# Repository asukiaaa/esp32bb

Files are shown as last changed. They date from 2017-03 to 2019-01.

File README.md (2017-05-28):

# ESP32BB
A kicad project for ESP-WROOM-32 and breadboard.

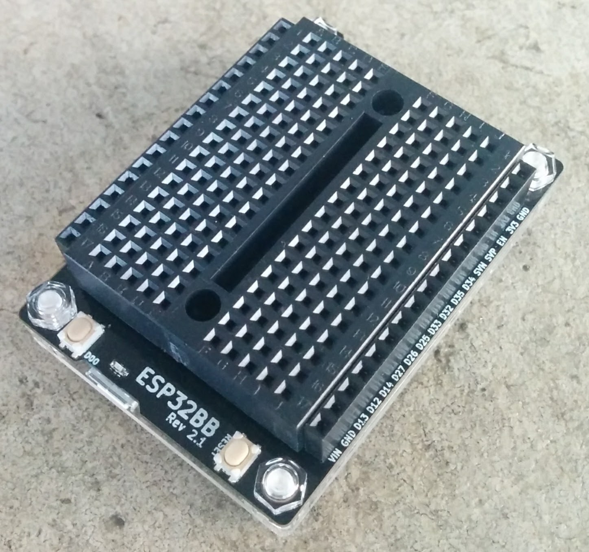
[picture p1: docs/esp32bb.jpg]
ESP32BB

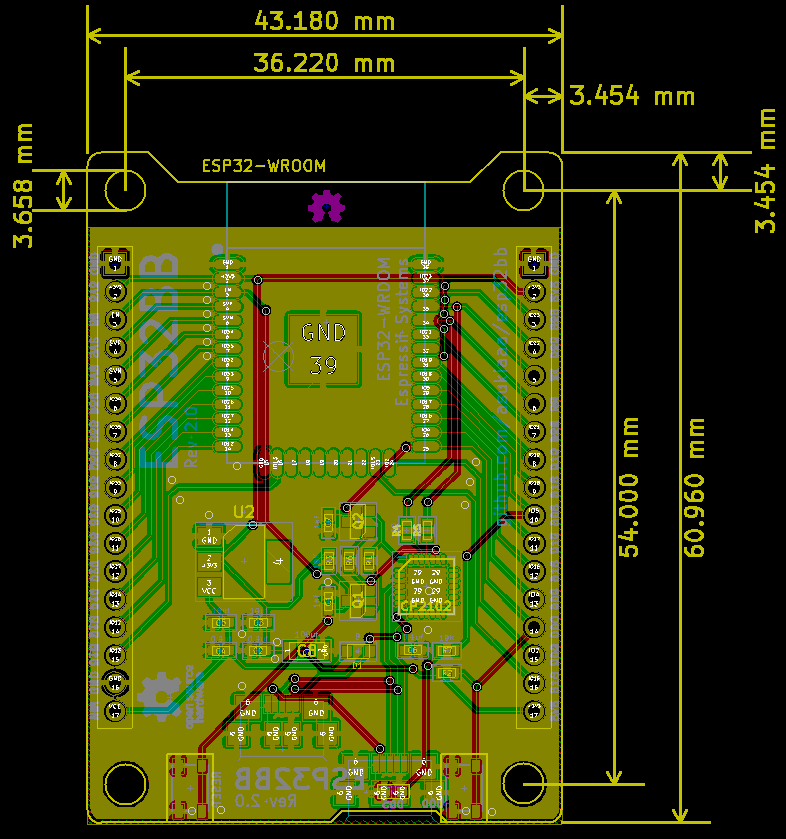
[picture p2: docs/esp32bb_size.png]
ESP32BB_size


[schema](/docs/esp32bb.pdf)

# Driver
This board uses CP2102 for serial communication.
For mac and windiws user, please install the following driver.
Linux supports cp2102 defaul, so linux user does not need any driver.

[CP210x USB to UART Bridge VCP Drivers](http://www.silabs.com/products/development-tools/software/usb-to-uart-bridge-vcp-drivers)

# Shop
[trial stacks](https://trialstacks.base.ec/items/6243312)

# Components
- [esp-wroop-32](http://akizukidenshi.com/catalog/g/gM-11647/)
- [Hirose-microB-USB](http://akizukidenshi.com/catalog/g/gC-05254/)
- [Diode](http://akizukidenshi.com/catalog/g/gI-05951/)
- [transistor MMBT3904](http://akizukidenshi.com/catalog/g/gI-05969/)
- [switch SKRPACE010](http://akizukidenshi.com/catalog/g/gP-06185/)
- [100uf 1206 condensor](http://akizukidenshi.com/catalog/g/gP-08260/)
- [10uf 0603 condensor](http://akizukidenshi.com/catalog/g/gP-07768/)
- [0.1uf 0603 condensor](http://akizukidenshi.com/catalog/g/gP-04940/)
- [1nf (1000pf) 0603 condensor](http://akizukidenshi.com/catalog/g/gP-09285/)
- [10k 0603 registor](http://akizukidenshi.com/catalog/g/gR-06103/)
- [led](http://akizukidenshi.com/catalog/g/gI-06417/)
- [Pin socket](http://akizukidenshi.com/catalog/g/gC-05779/)
- Bread board: [akizuki](http://akizukidenshi.com/catalog/g/gP-05158/) or [aliexpress](https://www.aliexpress.com/item/SYB-170-Mini-Prototype-Experiment-Test-Breadboard-Board-Tie-points-170-Tie-points-35-47-8/32595538101.html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)
- [CP2102](https://www.aliexpress.com/item/5pcs-Free-shipping-SILABS-CP2102-GMR-CP2102-QFN-28-offen-use-laptop-chip-100-new-original/32503317767.html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)
- [NCP1117ST33T3G](https://www.aliexpress.com/item/Free-Shipping-NCP1117ST33T3G-NCP1117-3-3V-linear-regulator-SOT-223-package/32244660148.html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)

# Footprints
- [ESP32-kiCAD-Footprints](https://github.com/adamjvr/ESP32-kiCAD-Footprints)
- [switch: SKRPACE010.kicad_mod](https://github.com/nosuz/kicad-lib/blob/master/module.pretty/SKRPACE010.kicad_mod)

# Programming software tools
ESP32BB is a ESP-WROOM-32 breakout board so you can write your own program by usinig the following tools.

- [espressif/arduino-esp32](https://github.com/espressif/arduino-esp32)
- [espressif/esp-idf](https://github.com/espressif/esp-idf)
- [Mongoose OS](https://mongoose-os.com/)

# License
MIT

# References
- [ESP32-Core-Board-V2_sch.pdf](http://akizukidenshi.com/download/ds/espressifsystems/ESP32-Core-Board-V2_sch.pdf)
- [esp_wroom_32_datasheet_en.pdf](https://espressif.com/sites/default/files/documentation/esp_wroom_32_datasheet_en.pdf)
- [Enginursday: First Impressions of the ESP32](https://www.sparkfun.com/news/2017)
- [ESP32 Development Board with TELEC Memorial photograph](https://macsbug.wordpress.com/2016/12/12/esp32-development-board-with-telec-memorial-photograph/)
- [DS_FT232R](http://www.ftdichip.com/Support/Documents/DataSheets/ICs/DS_FT232R.pdf)
- [SparkFun FTDI Basic Breakout - 3.3V](https://www.sparkfun.com/products/9873)
- [Sehematic of SparkFun FTDI Basic Breakout - 3.3V](http://cdn.sparkfun.com/datasheets/BreakoutBoards/FTDI%20Basic-v22-3.3V.pdf)
- [esp32-thing.sch](https://cdn.sparkfun.com/assets/learn_tutorials/5/0/7/esp32-thing-schematic.pdf)
- [The Internet of Things with ESP32](http://esp32.net/)
- [ESP-WROVER-KIT_SCH-2.pdf](https://dl.espressif.com/dl/schematics/ESP-WROVER-KIT_SCH-2.pdf)
- [ESP32-EVB_Rev_A.pdf](https://github.com/OLIMEX/ESP32-EVB/blob/master/HARDWARE/REV-A/ESP32-EVB_Rev_A.pdf)

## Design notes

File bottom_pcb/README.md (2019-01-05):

# bottom_pcb

- [esp32 hardware design guidelines](https://www.espressif.com/sites/default/files/documentation/esp32_hardware_design_guidelines_en.pdf)

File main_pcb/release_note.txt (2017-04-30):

# rev2.2
- Add diode for 3.3v power

# rev2.1
- Correct circuit around CP2102 chip

# rev2.0
- Replace to CP2102 from FT232RQ
- Remove SD card holder
- Change LED pin to D05
- Use 17pins header for both side

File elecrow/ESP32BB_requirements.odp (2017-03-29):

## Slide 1

Component labels

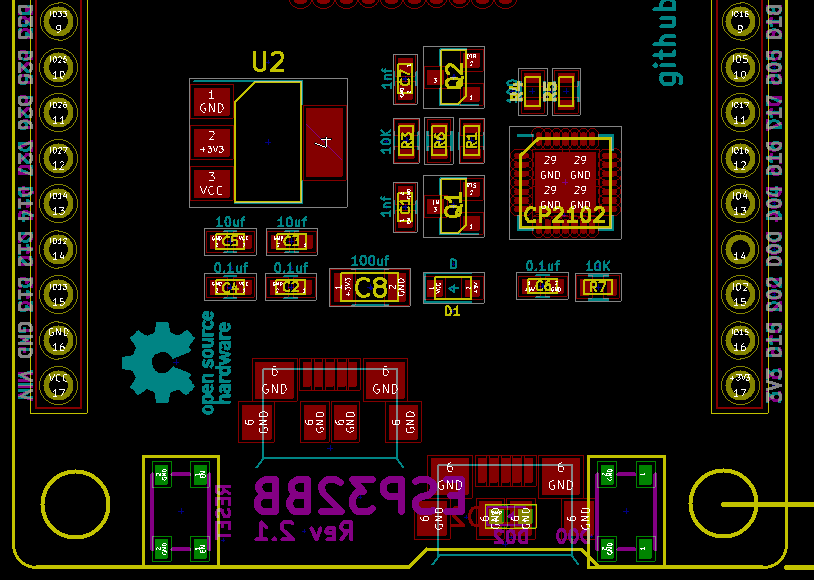
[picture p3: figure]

Front side

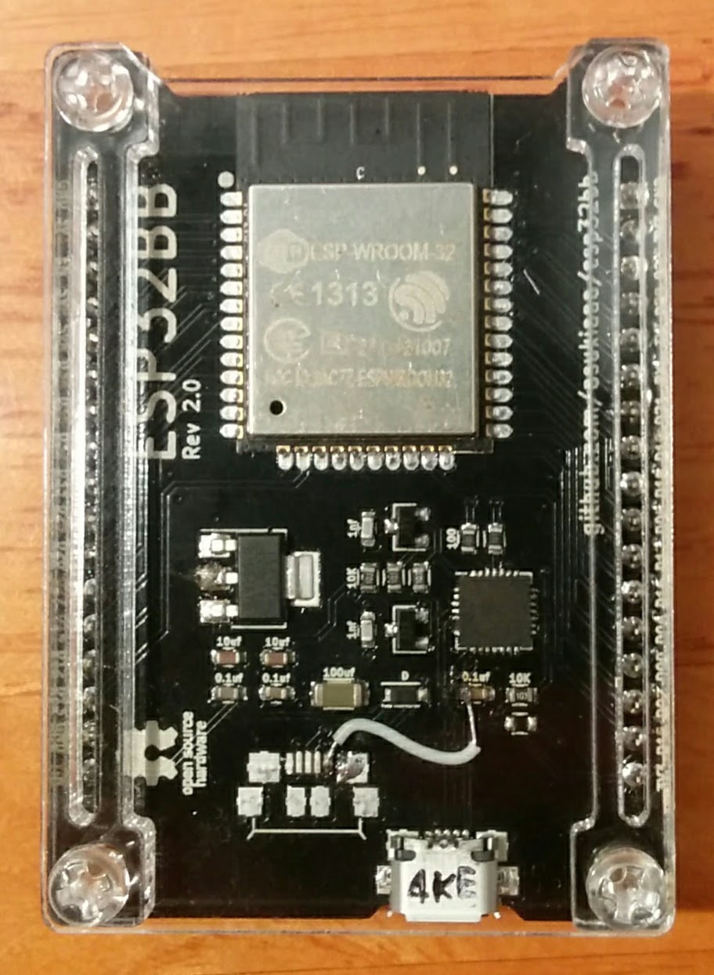
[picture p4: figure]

ESP32 module that has

TELEC mark

Back side

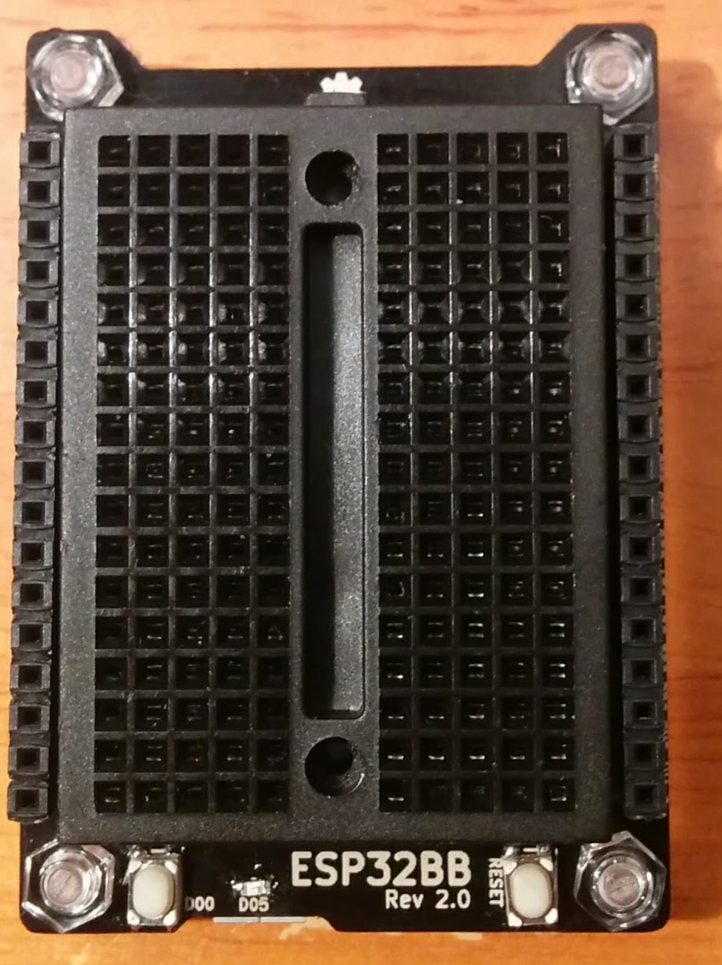
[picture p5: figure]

Please

ignore

bread

board

1x17

Pin

Socket

(female)

Diode

→

←

Diode

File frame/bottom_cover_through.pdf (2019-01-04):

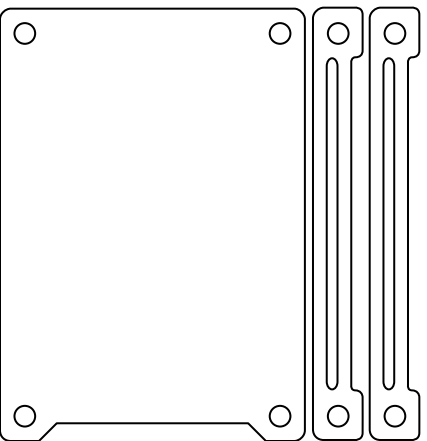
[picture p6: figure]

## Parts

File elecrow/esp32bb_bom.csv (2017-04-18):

Elecrow pn | Reference | Value | Footprint | url | memo
 | P3 | USB_OTG | usb_micro_b:USB_MICRO_B-HIROSE-ZX62R-B-5P | http://www.mouser.jp/ProductDetail/Hirose-Connector/ZX62R-B-5P/?qs=XQjbzJWzFPUqfCc9Mb2Taw==
1023510A(10K) | R1,R3,R6,R7 | 10K | Resistors_SMD:R_0603
 | D1 | D | Diodes_SMD:D_0805 | http://www.mouser.jp/ProductDetail/ROHM-Semiconductor/RSX101VA-30TR/?qs=4kLU8WoGk0tB41wg4aRbGQ==
2013010A(100nf) | C2,C4,C6 | 0.1uf | Capacitors_SMD:C_0603
2015010A(10uf) | C3,C5 | 10uf | Capacitors_SMD:C_0603
 | U1 | ESP32-WROOM | ESP32-footprints-Lib:ESP32-WROOM | http://akizukidenshi.com/catalog/g/gM-11850/ | Please use ESP-WROOM-32 module that has TELEC mark.
 | P1,P2 | CONN_01X17 | common:Pin_Header_Straight_1x17_Pitch2.54mm |  | Foot print is header(male) but use socket (female) component.
10240102A(100) | R4,R5 | 100 | Resistors_SMD:R_0603
4020290A | Q1,Q2 | MMBT3904 | TO_SOT_Packages_SMD:SOT-23
 | SW1,SW2 | SWITCH_SPST | switch:SKRPACE010 | http://www.mouser.jp/ProductDetail/ALPS/SKRPACE010/?qs=m0BA540hBPehI%2flbUxNGuw==
4040706A(green) | D2 | D02 | LEDs:LED_0603
2011501A(1nf) | C1,C7 | 1nf | Capacitors_SMD:C_0603
 | C8 | 100uf | Capacitors_SMD:C_1206 | http://www.mouser.jp/ProductDetail/Taiyo-Yuden/JMK316ABJ107ML-T/?qs=CNQs48zzdnrnxCTArzOO1A==
 | U3 | CP2102 | Housings_DFN_QFN:QFN-28-1EP_5x5mm_Pitch0.5mm | http://www.mouser.jp/ProductDetail/Silicon-Labs/CP2102N-A01-GQFN28/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
 | U2 | NCP1117ST33T3G | TO_SOT_Packages_SMD:SOT-223 | http://www.mouser.jp/ProductDetail/ON-Semiconductor/NCP1117ST33T3G/

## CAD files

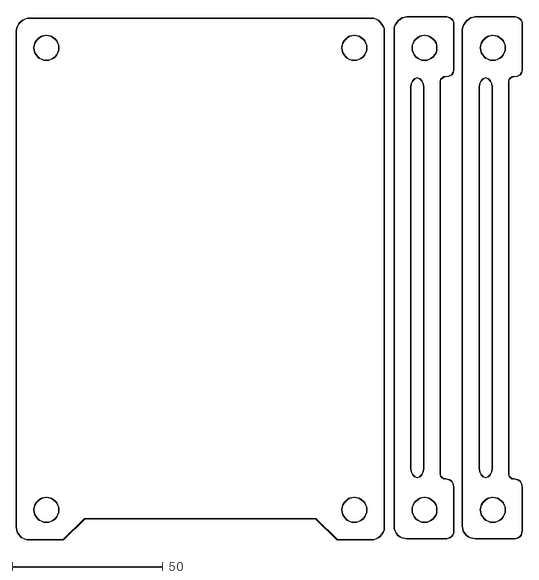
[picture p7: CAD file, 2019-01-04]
frame/bottom_cover_through.dxf
167.7 x 173.6

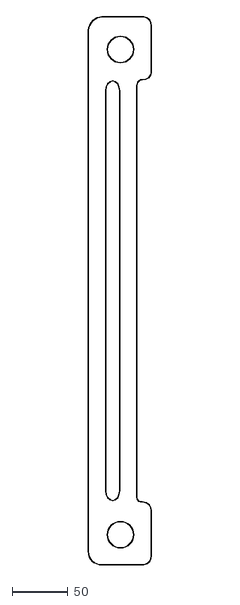
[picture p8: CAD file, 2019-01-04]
frame/bottom_cover_through_7x61x3mm.dxf
56.4 x 490.9

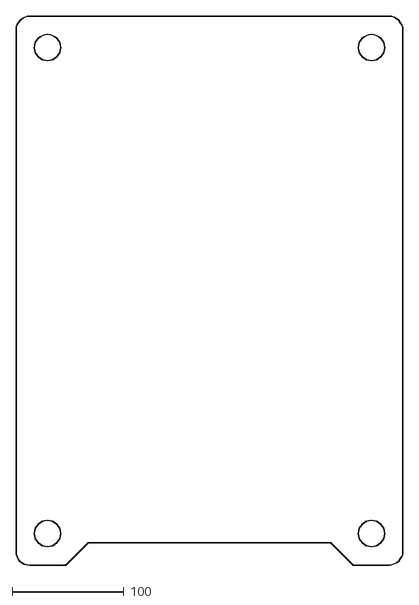
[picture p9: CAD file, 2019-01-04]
frame/bottom_cover_through_42x61x2mm.dxf
345.5 x 490.3

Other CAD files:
frame/export/bottom_cover_through.dxf
frame/export/bottom_cover_through_42x61x2mm.dxf
frame/export/bottom_cover_through_7x61x3mm.dxf

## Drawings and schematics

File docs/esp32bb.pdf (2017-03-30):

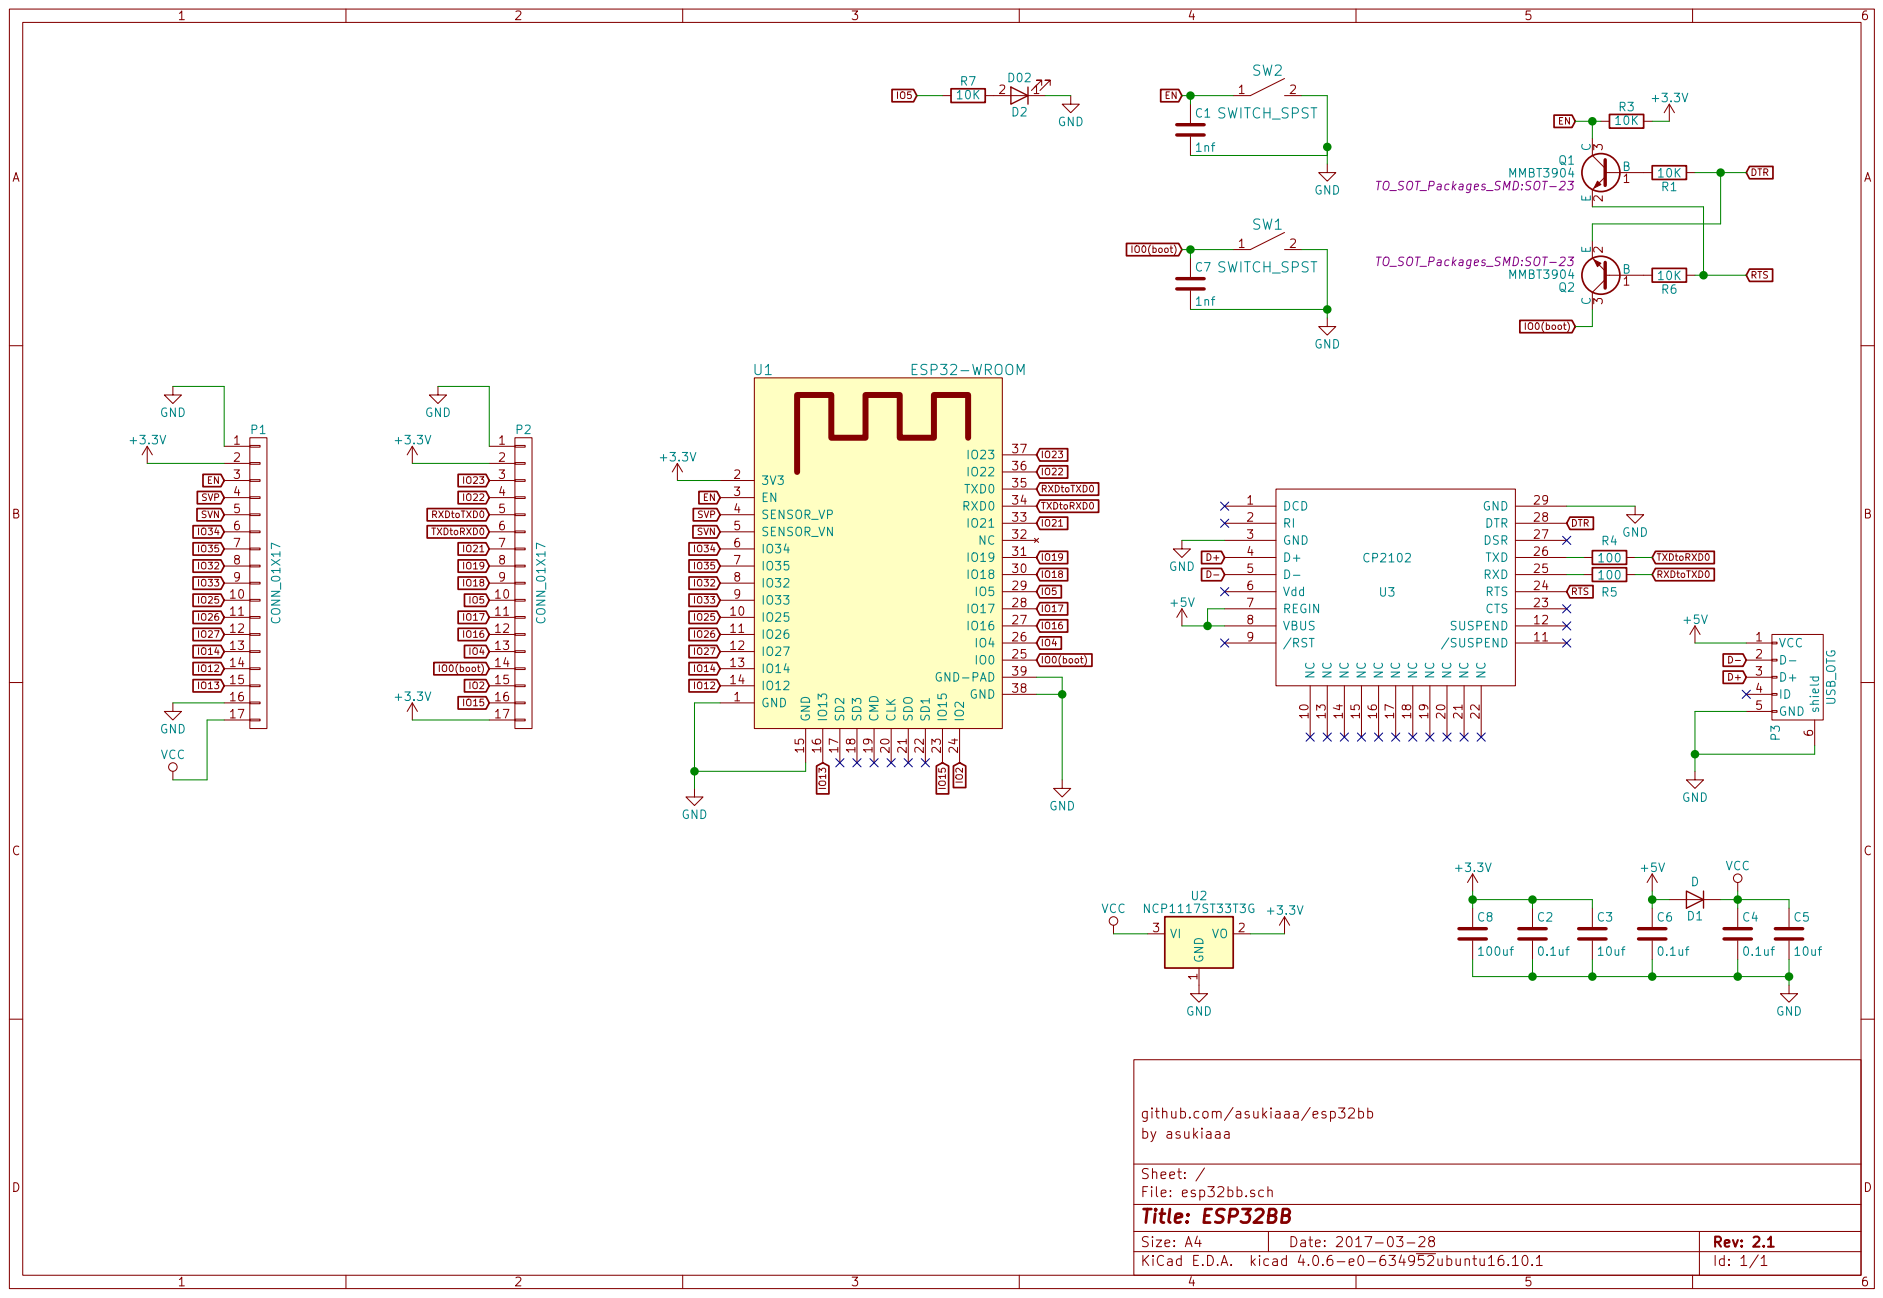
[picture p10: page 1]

github.com/asukiaaa/esp32bb
File: esp32bb.sch Sheet: / by asukiaaa

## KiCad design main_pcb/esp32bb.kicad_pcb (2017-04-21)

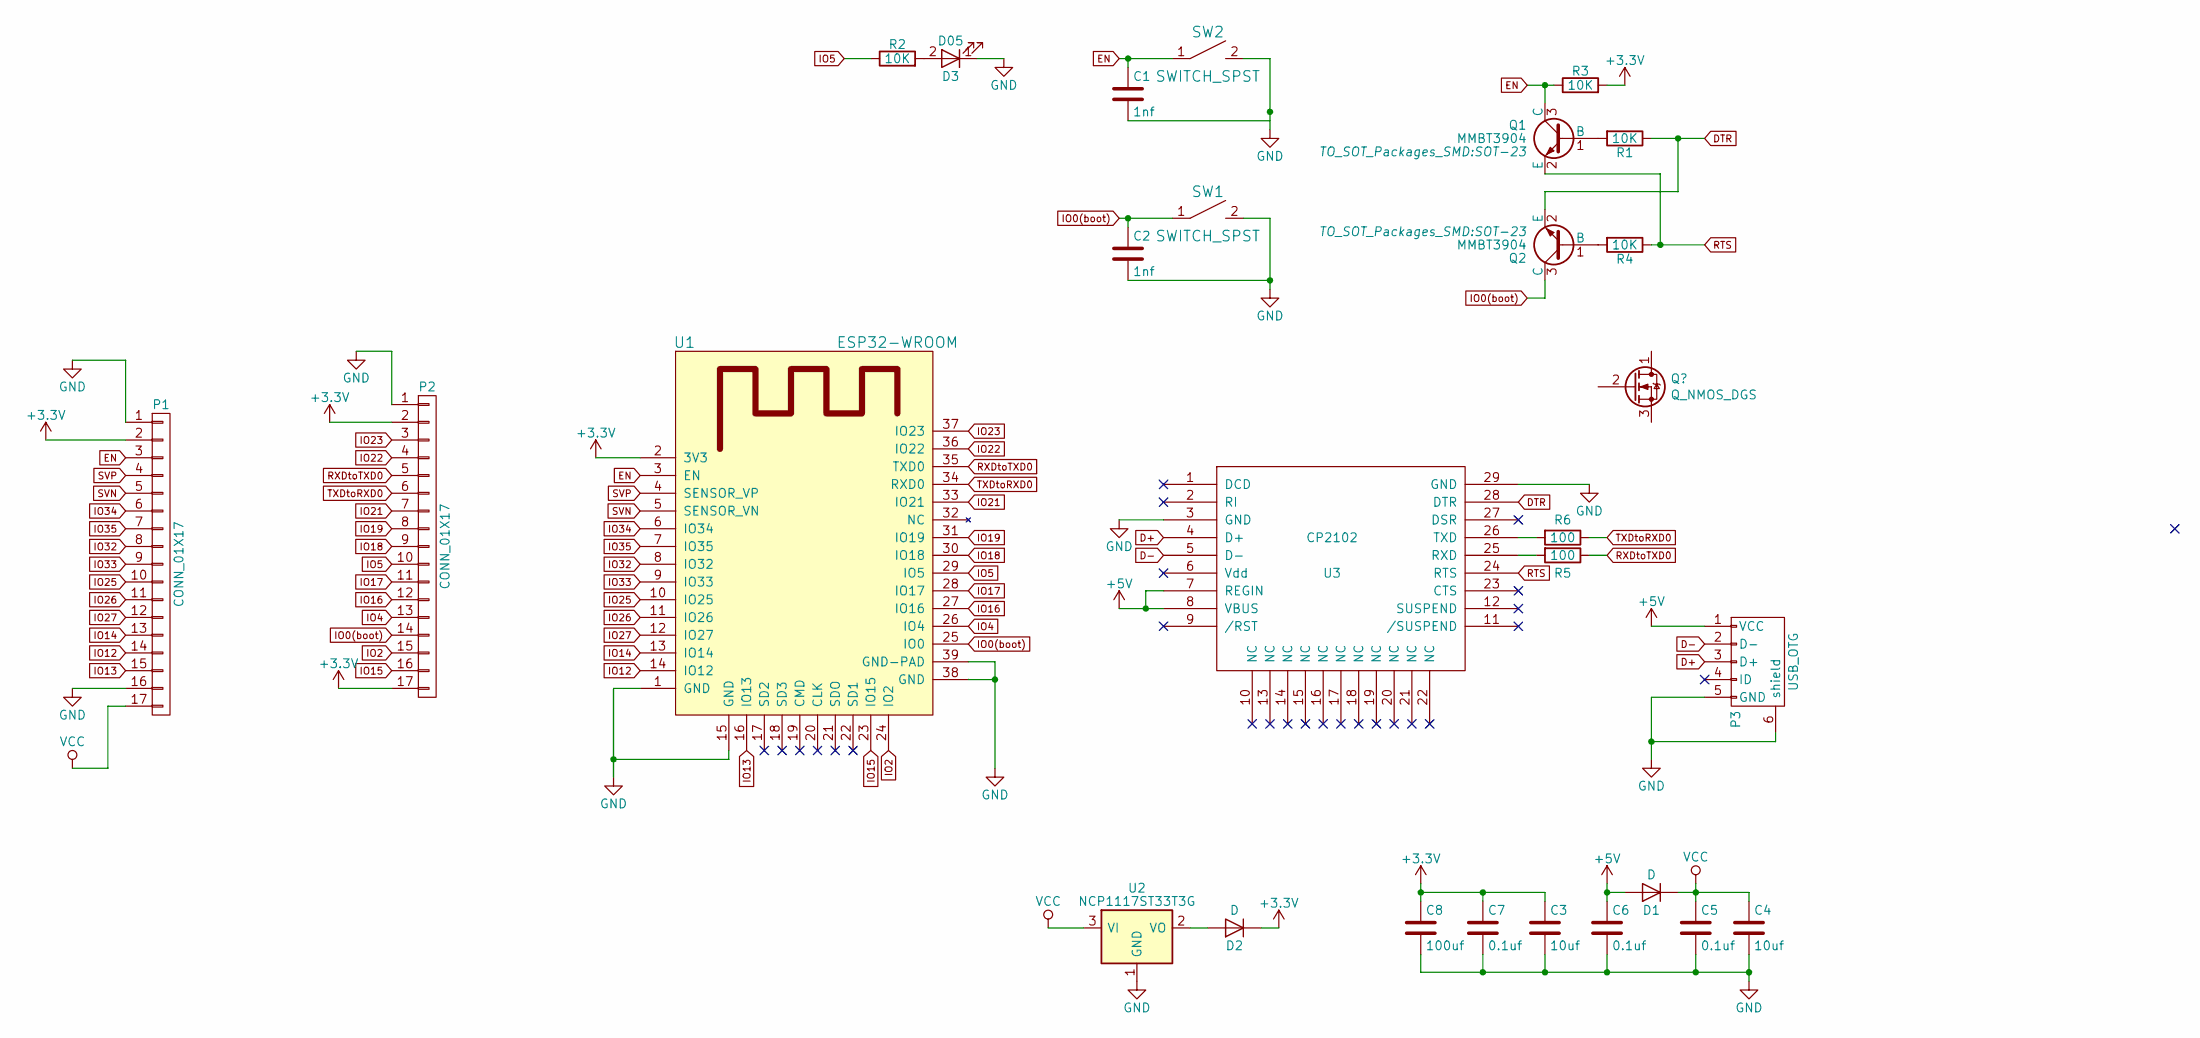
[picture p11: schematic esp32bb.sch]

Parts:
C1, C2: 1nf; C_0603
C3, C4: 10uf; C_0603
C5, C6, C7: 0.1uf; C_0603
C8: 100uf; C_1206
D1, D2: D; D_0805
D3: D05; LED_0603
P1, P2: CONN_01X17; Pin_Header_Straight_1x17_Pitch2.54mm
P3: USB_OTG; USB_MICRO_B-HIROSE-ZX62R-B-5P
Q1, Q2: MMBT3904; SOT-23
R1, R2, R3, R4: 10K; R_0603
R5, R6: 100; R_0603
SW1, SW2: SWITCH_SPST; SKRPACE010
U1: ESP32-WROOM
U2: NCP1117ST33T3G; SOT-223
U3: CP2102; QFN-28-1EP_5x5mm_Pitch0.5mm

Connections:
+3V3: C3.1, C7.1, C8.1, D2.1 (K), P1.2, P2.2, P2.17, R3.2, U1.2 (3V3)
+5V: C6.1, D1.2 (A), P3.1 (VCC), U3.7 (REGIN), U3.8 (VBUS); also elsewhere on the board
D+: P3.3 (D+), U3.4 (D+); also elsewhere on the board
D-: P3.2 (D-), U3.5 (D-); also elsewhere on the board
DTR: Q2.2 (E), R1.1, U3.28 (DTR)
EN: C1.1, P1.3, Q1.3 (C), R3.1, SW2.1, U1.3 (EN)
GND: C1.2, C2.2, C3.2, C4.2, C5.2, C6.2, C7.2, C8.2, D3.1 (K), P1.1, P1.16, P2.1, P3.5 (GND), P3.6 (shield), SW1.2, SW2.2, U1.1 (GND), U1.15 (GND), U1.38 (GND), U1.39 (GND-PAD), U2.1 (GND), U3.3 (GND), U3.29 (GND); also elsewhere on the board
IO0(boot): C2.1, P2.14, Q2.3 (C), SW1.1, U1.25 (IO0)
IO2: P2.15, U1.24 (IO2)
IO4: P2.13, U1.26 (IO4)
IO5: P2.10, R2.1, U1.29 (IO5)
IO12: P1.14, U1.14 (IO12)
IO13: P1.15, U1.16 (IO13)
IO14: P1.13, U1.13 (IO14)
IO15: P2.16, U1.23 (IO15)
IO16: P2.12, U1.27 (IO16)
IO17: P2.11, U1.28 (IO17)
IO18: P2.9, U1.30 (IO18)
IO19: P2.8, U1.31 (IO19)
IO21: P2.7, U1.33 (IO21)
IO22: P2.4, U1.36 (IO22)
IO23: P2.3, U1.37 (IO23)
IO25: P1.10, U1.10 (IO25)
IO26: P1.11, U1.11 (IO26)
IO27: P1.12, U1.12 (IO27)
IO32: P1.8, U1.8 (IO32)
IO33: P1.9, U1.9 (IO33)
IO34: P1.6, U1.6 (IO34)
IO35: P1.7, U1.7 (IO35)
unnamed: D2.2 (A), U2.2 (VO)
unnamed: D3.2 (A), R2.2
unnamed 31: P3.4 (ID); also elsewhere on the board
unnamed: Q1.1 (B), R1.2
unnamed: Q2.1 (B), R4.2
unnamed: R5.2, U3.25 (RXD)
unnamed: R6.2, U3.26 (TXD)
RTS: Q1.2 (E), R4.1, U3.24 (RTS)
RXDtoTXD0: P2.5, R5.1, U1.35 (TXD0)
SVN: P1.5, U1.5 (SENSOR_VN)
SVP: P1.4, U1.4 (SENSOR_VP)
TXDtoRXD0: P2.6, R6.1, U1.34 (RXD0)
VCC: C4.1, C5.1, D1.1 (K), P1.17, U2.3 (VI)

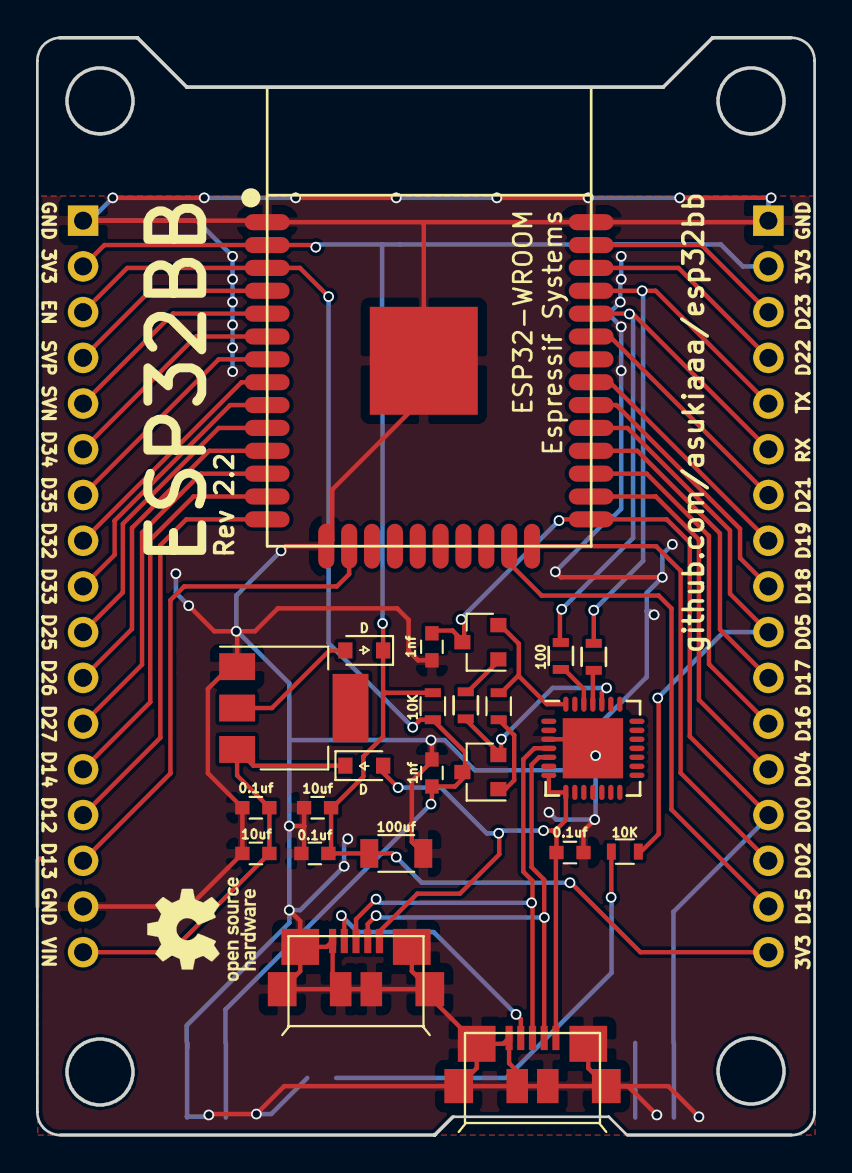
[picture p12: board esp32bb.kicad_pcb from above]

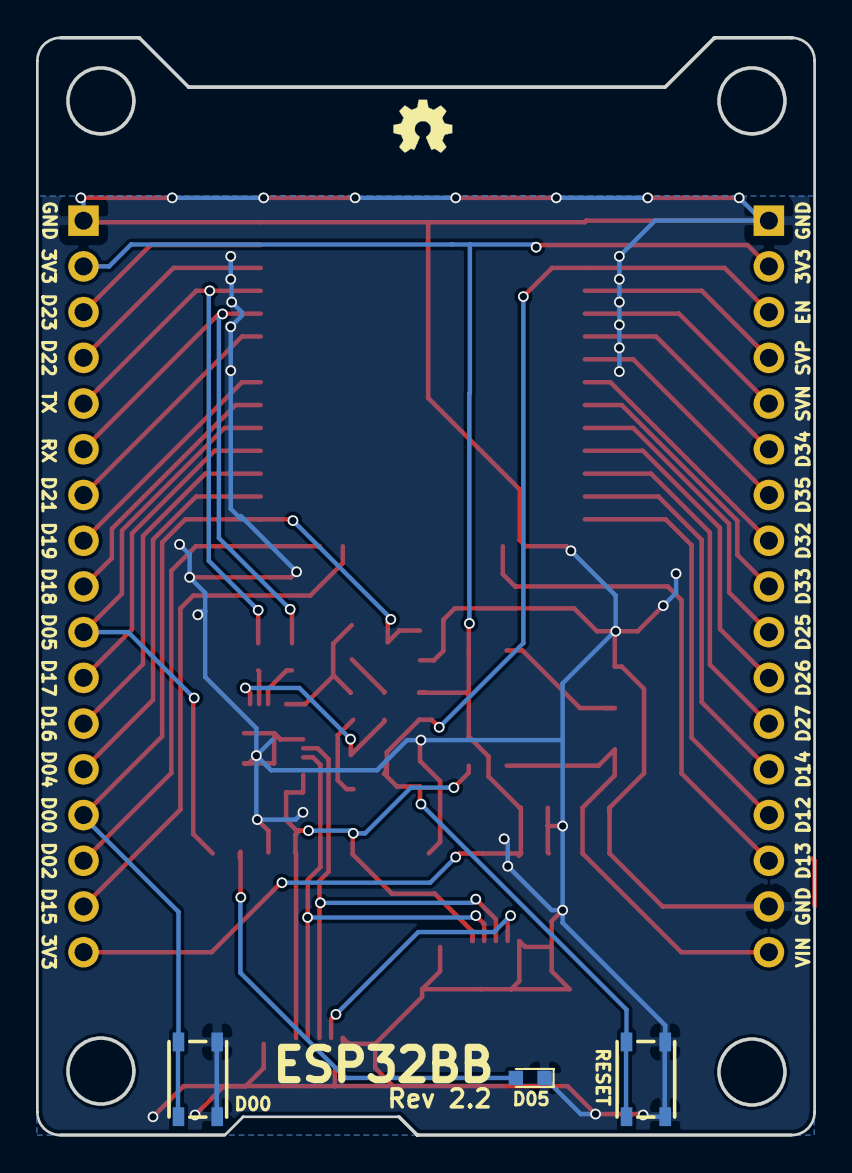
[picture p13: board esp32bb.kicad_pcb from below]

Board: 2 copper layers, 43.2 x 61.0 mm, 28 parts (5 on the bottom side), 42 nets.

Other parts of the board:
P3#2: USB_OTG; USB_MICRO_B-HIROSE-ZX62R-B-5P

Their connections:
+5V: P3#2.1; also elsewhere on the board
D+: P3#2.3; also elsewhere on the board
D-: P3#2.2; also elsewhere on the board
GND: P3#2.5, P3#2.6; also elsewhere on the board
unnamed 31: P3#2.4; also elsewhere on the board

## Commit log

2017-01-04 Add link about sparkfun FTDI breakout board
2017-01-05 Put wroom-32 and ftdi to schema
    [esp-wroom-32-break.kicad_pcb, esp-wroom-32-break.sch]
2017-01-07 Change files place
    [esp-wroom-32-break.kicad_pcb, esp-wroom-32-break.sch]
2017-02-03 Update schema with using 18 pins connectors etc
    [esp-wroom-32-break.sch]
2017-02-05 Assign component footprints and generated net file
    [esp-wroom-32-break.kicad_pcb, esp-wroom-32-break.sch]
2017-02-06 Put footprints
    [_saved_esp-wroom-32-break.sch, esp-wroom-32-break.kicad_pcb]
2017-02-06 Created revision 1.0 pcb
    [esp-wroom-32-break.kicad_pcb]
2017-02-08 Add plot files to order to elecrow
    [_saved_esp-wroom-32-break.sch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]
2017-02-18 Correct pin name on back silk
    [esp-wroom-32-break.kicad_pcb]
2017-02-18 Change to 17 pins socket and remove redundant condensors
    [esp-wroom-32-break.sch]
2017-02-19 Update schema and netlist with adding auto reset circuit
    [esp-wroom-32-break.sch]
2017-02-20 Put footprints for rev1.1
    [esp-wroom-32-break.kicad_pcb, esp-wroom-32-break.sch]
2017-02-20 Change led and silk layout
    [esp-wroom-32-break.kicad_pcb]
2017-02-20 Update plots to order for elecrow
    [esp-wroom-32-break.kicad_pcb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]
2017-02-25 Add registers to pull up SD signals and reset button etc
    [esp-wroom-32-break.kicad_pcb, esp-wroom-32-break.sch]
2017-02-25 Update plots for rev1.2
    [esp-wroom-32-break-B.Cu.gbl, esp-wroom-32-break-B.Mask.gbs, esp-wroom-32-break-B.SilkS.gbo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]
2017-03-01 Rename project name to esp32bb
    [esp32bb.kicad_pcb, esp32bb.sch]
2017-03-02 Prepare docs for releasing rev1.2
    [esp32bb.kicad_pcb, esp32bb.sch]
2017-03-03 Add RX TX to headers
    [esp32bb.kicad_pcb, esp32bb.sch]
2017-03-03 Show component number on fab layer
    [esp32bb.kicad_pcb, esp32bb.sch]
2017-03-03 Update plot files for rev1.3
    [esp-wroom-32-break-F.Cu.gtl, esp32bb-B.Cu.gbl, esp32bb-B.Mask.gbs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]
2017-03-04 Update hole position
    [esp32bb.kicad_pcb]
2017-03-04 Update plots for new hole position
    [esp32bb-B.Cu.gbl, esp32bb-B.Mask.gbs, esp32bb-B.SilkS.gbo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]
2017-03-06 Change holls size and position and add dimension
    [esp32bb.kicad_pcb]
2017-03-06 Update plot files for rev1.4
    [esp32bb-B.Cu.gbl, esp32bb-B.Mask.gbs, esp32bb-B.SilkS.gbo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]
2017-03-07 Add keep out area for SD card holder
    [esp32bb.kicad_pcb]
2017-03-08 Update plots for rev1.4 with setting keepout area for SD card holder
    [esp32bb-B.Cu.gbl, esp32bb-B.Mask.gbs, esp32bb-B.SilkS.gbo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]
2017-03-10 Update schema pdf
    [esp32bb.sch]
2017-03-11 Update kicad_pcb revision to 1.4
    [esp32bb.kicad_pcb]
2017-03-11 Add pin socket and bread board info to readme
2017-03-13 Add foot_plate as a frame
2017-03-18 Update schema to use CP2102 and NCP1117DT33 and remove SD card holder
    [esp32bb.kicad_pcb, esp32bb.sch]
2017-03-19 Update pcb for rev2.0
    [esp32bb.kicad_pcb, esp32bb.sch]
2017-03-19 Update plots to order rev2.0 PCB
    [esp32bb-B.Cu.gbl, esp32bb-B.Mask.gbs, esp32bb-B.SilkS.gbo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]
2017-03-28 Correct and update schema and pcb for rev2.1
    [esp32bb.kicad_pcb, esp32bb.sch]
2017-03-29 Update plots for rev2.1
    [esp32bb-B.Cu.gbl, esp32bb-B.Mask.gbs, esp32bb-B.SilkS.gbo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]
2017-03-29 Update bom for rev2.1
    [esp32bb_bom.csv]
2017-03-29 Add requirements file for rev2.1 to order PCBA service for elecrow
2017-04-18 Back hirose micro-USB to readme and bom
    [esp32bb_bom.csv]
2017-04-18 Correct led label to D05
    [esp32bb.kicad_pcb]
2017-04-19 Modify ground zone
    [esp32bb.kicad_pcb]
2017-04-20 Correct label of led on schema
    [esp32bb.sch]
2017-04-21 Add diode for 3v3 and modify label for registers and condensors
    [esp32bb.kicad_pcb, esp32bb.sch]
2017-05-02 Change hole position on bottom cover
2017-05-28 Add driver info
2019-01-04 Create main_pcb directory
    [esp32bb.kicad_pcb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]
2019-01-04 Add frame data
    [bottom_cover_through.dxf, bottom_cover_through_42x61x2mm.dxf, bottom_cover_through_7x61x3mm.dxf]
2019-01-05 Add bottom pcb
    [bottom_pcb-B.Cu.gbr, bottom_pcb-B.Mask.gbr, bottom_pcb-B.Paste.gbr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]
2019-01-18 Add spacer_pcb
    [spacer_pcb-B.Cu.gbr, spacer_pcb-B.Mask.gbr, spacer_pcb-B.Paste.gbr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]
2019-01-18 Correct size of bottom pcb
    [bottom_pcb-B.Cu.gbr, bottom_pcb-B.Mask.gbr, bottom_pcb-B.Paste.gbr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]
